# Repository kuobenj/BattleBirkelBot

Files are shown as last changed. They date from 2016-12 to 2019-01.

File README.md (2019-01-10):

# BirkelBot Battlebot Repo
This repository is for the code and other files related to Team Unobtanium's Battlebot for the Combotics competition held annually at the University of Illinois at Urbana Champaign.

Team Unobtanium is:
* Matt Birkel - Team Captain, Mechanical Design, Software
* Benjamin Kuo - Electrical Design, Software

### Folder Structure
* Robot - This is robot side code. For now this should largely be arduino code for the arduino on board the robot.
* DriverStation - This is the operator side code. This is the code that runs on a driverstation computer.
* Arduino_Calibration_Stuff - This is a folder for a tool to use the arduino to calibrate ESC's
* PCB_files is a directory that holds the EAGLE files for the custom "motherboard" for the robot. This directory also features a reworked design of a PCB for hall effect sensors to sensor 35mm outrunner brushless motors.

### Dependencies
The Robot code is written for an Arduino Pro Mini. As such the Arduino IDE is required to compile and upload the Arduino-side code. The Arduino IDE offers a variety of Libraries for use. This project utilizes

* Encoder by Paul Stoffregen (version 1.4.1)
* PID by Brett Beauregard (version 1.2.0)

To install these libraries

- Go to 'Sketch' -> 'Include Library' -> 'Manage Libraries...'
- Search '<package-name>'
- Install '<package-name>'

The DriverStation code is a pythons script. Below are a potentially non-exhaustive list of the required dependencies.

* pygame - For grabbing joystick values
* serial - For writing to the serial out for the Xbee communication

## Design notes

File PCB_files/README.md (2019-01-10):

The sensor_35mm files are all inspired by Equals Zero Designs

"Mount CAD" directory is for the mount to the motor for the sensors

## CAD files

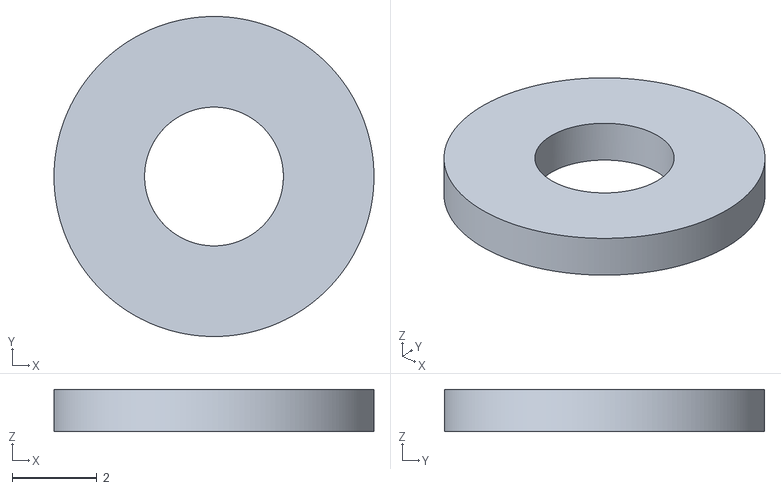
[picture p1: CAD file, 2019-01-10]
PCB_files/Mount CAD/ANSI_4_x_1_mm.stl
7.56 x 7.56 x 1.00

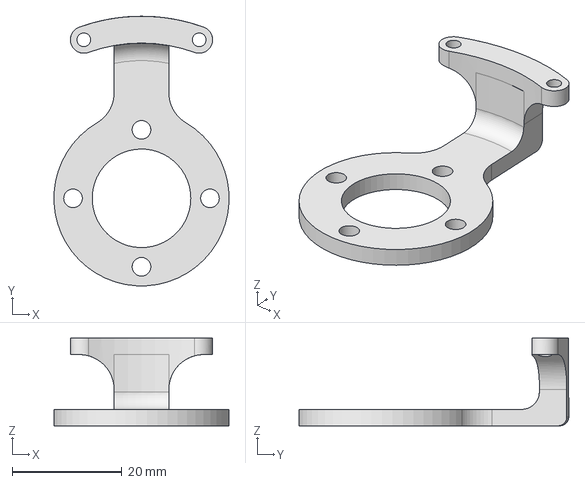
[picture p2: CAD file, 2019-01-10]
PCB_files/Mount CAD/SensorMount.stp
32.0 x 49.2 x 16.0 mm

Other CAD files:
PCB_files/Mount CAD/SensorMount.ipt
PCB_files/Mount CAD/SensorMount.stl

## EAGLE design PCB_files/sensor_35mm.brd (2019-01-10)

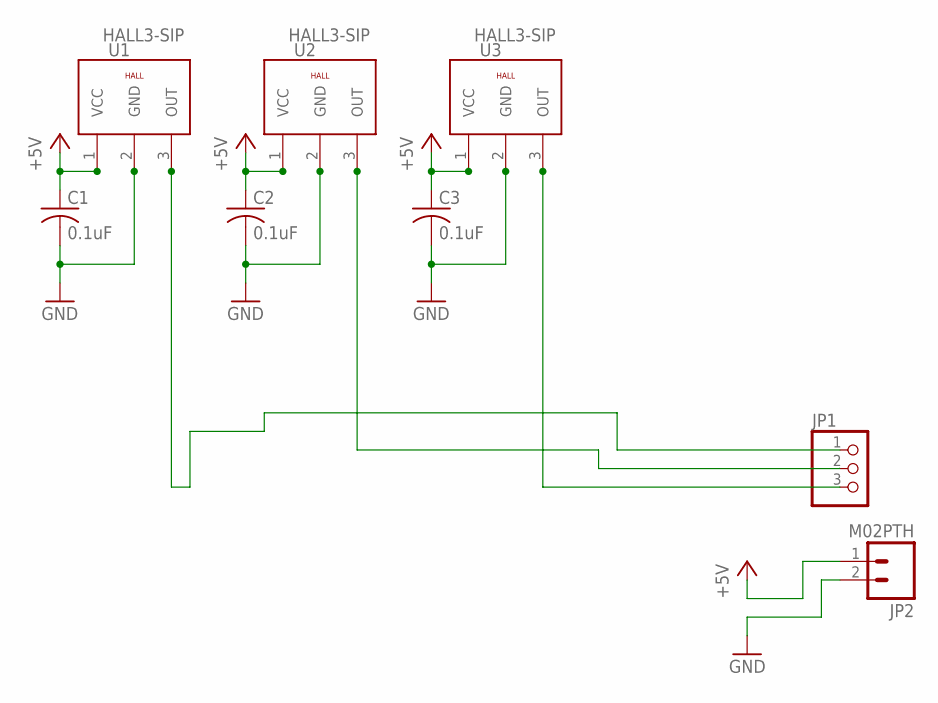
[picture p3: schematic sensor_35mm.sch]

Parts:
C1, C2, C3: 0.1uF; C0603
JP1: PINHD-1X3CB; 1X03-CLEANBIG
JP2: M02PTH; 1X02
U1, U2, U3: HALL3-SIP; 3PINS1,27

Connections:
+5V: C1.1, C2.1, C3.1, JP2.1, U1.1 (VCC), U2.1 (VCC), U3.1 (VCC)
GND: C1.2, C2.2, C3.2, JP2.2, U1.2 (GND), U2.2 (GND), U3.2 (GND)
unnamed: JP1.1, U1.3 (OUT)
unnamed: JP1.3, U3.3 (OUT)
unnamed: JP1.2, U2.3 (OUT)

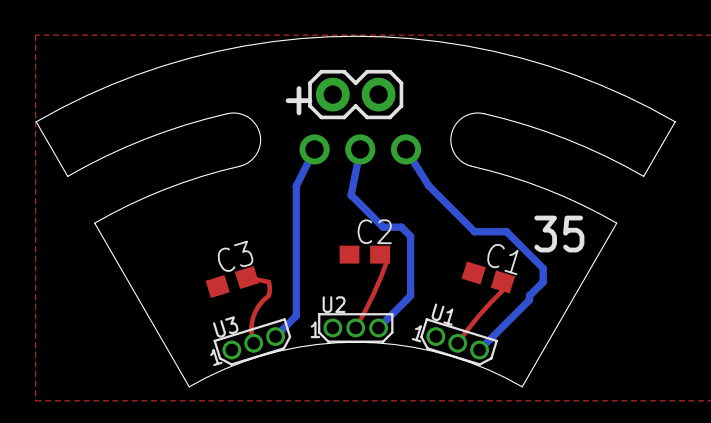
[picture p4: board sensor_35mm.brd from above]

Board: 2 copper layers, 35.5 x 19.5 mm, 8 parts (0 on the bottom side), 5 nets.

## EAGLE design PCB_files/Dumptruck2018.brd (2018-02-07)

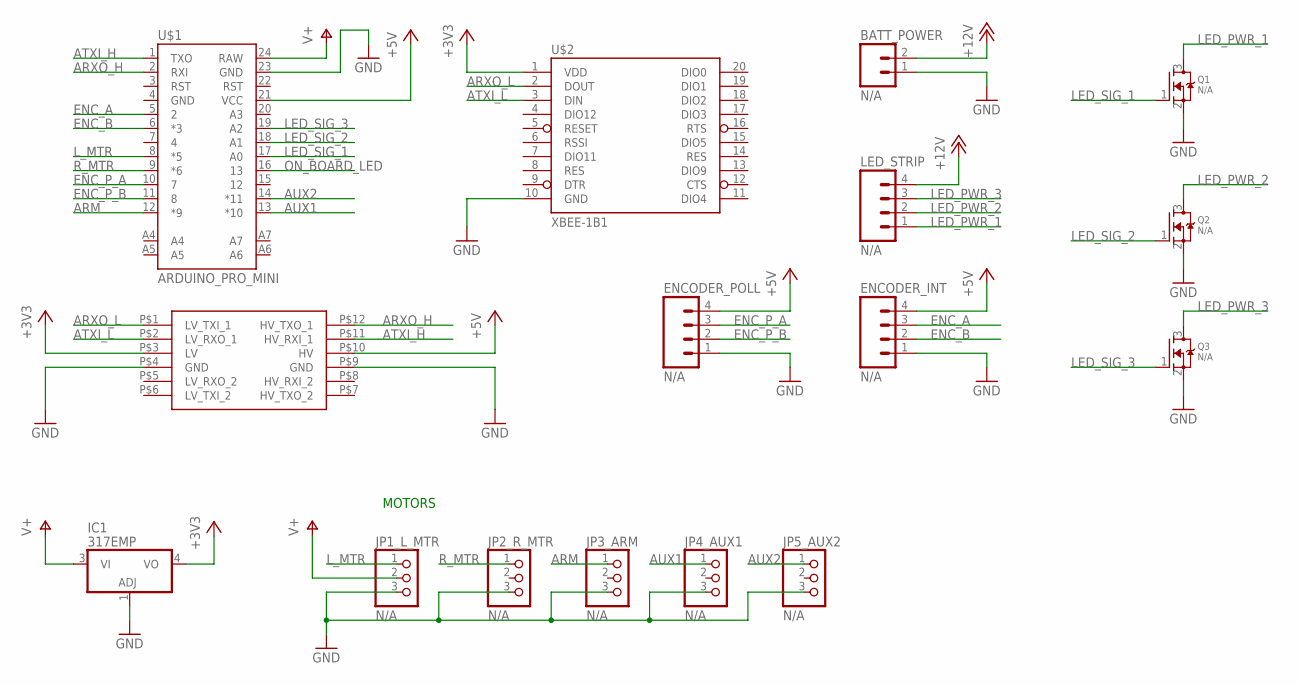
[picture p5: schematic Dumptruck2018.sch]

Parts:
BATT_POWER: N/A; 1X02
ENCODER_INT: N/A; 1X04_LOCK
ENCODER_POLL: N/A; 1X04_LOCK
IC1: 317EMP; SOT223
JP1_L_MTR, JP2_R_MTR, JP3_ARM, JP4_AUX1, JP5_AUX2: N/A; 1X03
LED_STRIP: N/A; 1X04_LOCK
Q1, Q2, Q3: N/A; SOT23
U$1: ARDUINO_PRO_MINI
U$2: XBEE-1B1; XBEE-1
U$3: LOGIC_LEVEL_CONVERTER

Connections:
+3V3: IC1.4 (VO), U$2.1 (VDD), U$3.P$3 (LV)
+5V: ENCODER_INT.4, ENCODER_POLL.4, U$1.21 (VCC), U$3.P$10 (HV)
+12V: BATT_POWER.2, LED_STRIP.4
ARM: JP3_ARM.1, U$1.12 (*9)
ARXO_H: U$1.2 (RXI), U$3.P$12 (HV_TXO_1)
ARXO_L: U$2.2 (DOUT), U$3.P$1 (LV_TXI_1)
ATXI_H: U$1.1 (TXO), U$3.P$11 (HV_RXI_1)
ATXI_L: U$2.3 (DIN), U$3.P$2 (LV_RXO_1)
AUX1: JP4_AUX1.1, U$1.13 (*10)
AUX2: JP5_AUX2.1, U$1.14 (*11)
ENC_A: ENCODER_INT.3, U$1.5 (2)
ENC_B: ENCODER_INT.2, U$1.6 (*3)
ENC_P_A: ENCODER_POLL.3, U$1.10 (7)
ENC_P_B: ENCODER_POLL.2, U$1.11 (8)
GND: BATT_POWER.1, ENCODER_INT.1, ENCODER_POLL.1, IC1.1 (ADJ), JP1_L_MTR.3, JP2_R_MTR.3, JP3_ARM.3, JP4_AUX1.3, JP5_AUX2.3, Q1.2 (S), Q2.2 (S), Q3.2 (S), U$1.23 (GND), U$2.10 (GND), U$3.P$4 (GND), U$3.P$9 (GND)
LED_PWR_1: LED_STRIP.1, Q1.3 (D)
LED_PWR_2: LED_STRIP.2, Q2.3 (D)
LED_PWR_3: LED_STRIP.3, Q3.3 (D)
LED_SIG_1: Q1.1 (G), U$1.17 (A0)
LED_SIG_2: Q2.1 (G), U$1.18 (A1)
LED_SIG_3: Q3.1 (G), U$1.19 (A2)
L_MTR: JP1_L_MTR.1, U$1.8 (*5)
ON_BOARD_LED: U$1.16 (13)
R_MTR: JP2_R_MTR.1, U$1.9 (*6)
V+: IC1.3 (VI), JP1_L_MTR.2, U$1.24 (RAW)

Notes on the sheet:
MOTORS

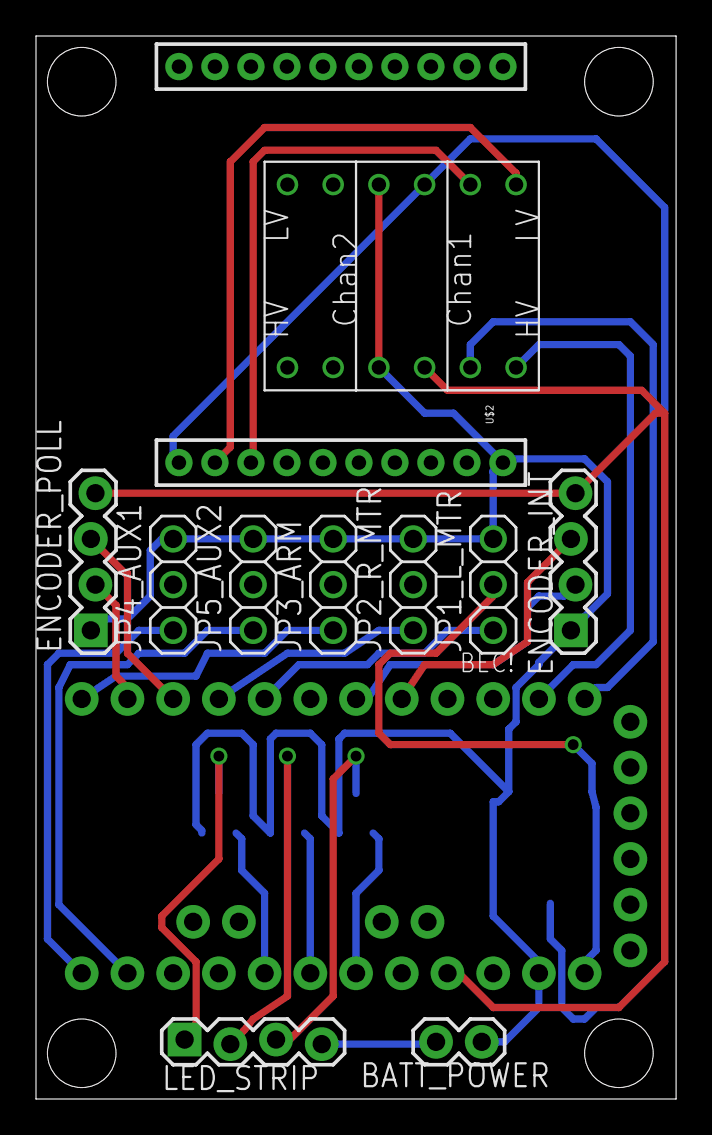
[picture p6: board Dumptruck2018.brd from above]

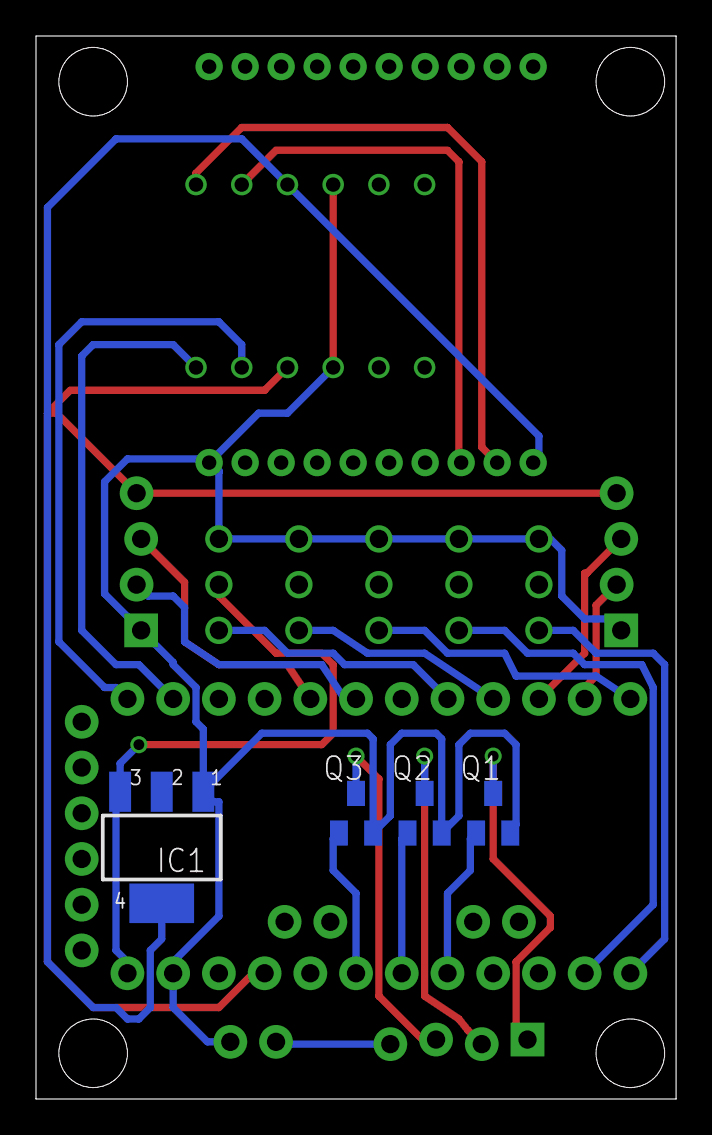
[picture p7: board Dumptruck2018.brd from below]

Board: 2 copper layers, 35.6 x 59.1 mm, 16 parts (4 on the bottom side), 24 nets.

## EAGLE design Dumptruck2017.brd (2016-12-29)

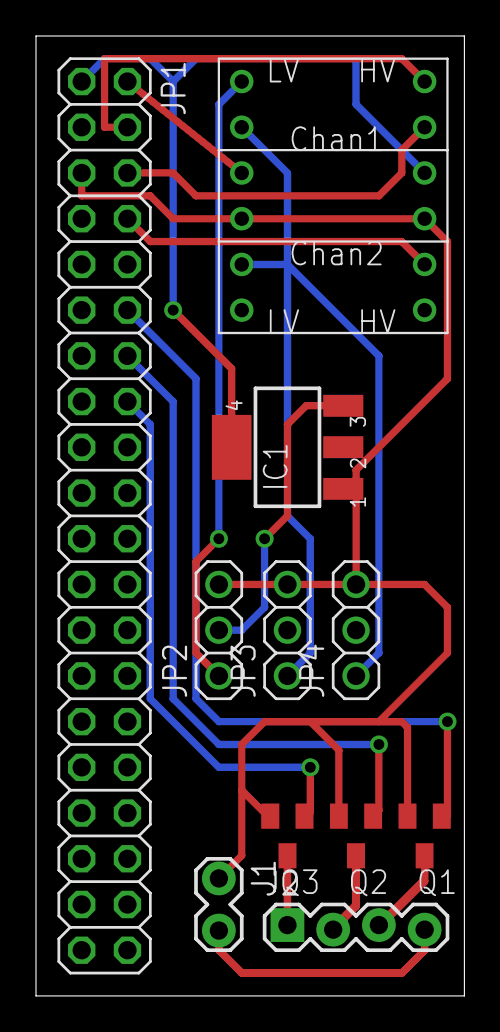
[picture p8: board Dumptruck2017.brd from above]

Board: 2 copper layers, 23.8 x 53.3 mm, 11 parts (0 on the bottom side), 17 nets.

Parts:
IC1: 317EMP; SOT223
J1: 1X02_LOCK
J2: 1X04_LOCK
JP1: 2X20
JP2, JP3, JP4: 1X03
Q1, Q2, Q3: SOT23
U$1: LOGIC_LEVEL_CONVERTER

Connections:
+3V3: JP1.2, U$1.P$3
+5V: IC1.4, JP1.1, U$1.P$10
+12V: J1.2, J2.4
+24V: IC1.3, JP2.2
ARM_MTR_H: JP4.1, U$1.P$5
ARM_MTR_L: JP1.8, U$1.P$8
GND: IC1.1, J1.1, JP1.5, JP2.3, JP3.3, JP4.3, Q1.2, Q2.2, Q3.2, U$1.P$4, U$1.P$9
LED1_PWR: J2.3, Q1.3
LED1_SIG: JP1.12, Q1.1
LED2_PWR: J2.2, Q2.3
LED2_SIG: JP1.14, Q2.1
LED3_PWR: J2.1, Q3.3
LED3_SIG: JP1.16, Q3.1
L_MTR_H: JP2.1, U$1.P$1
L_MTR_L: JP1.4, U$1.P$12
R_MTR_H: JP3.1, U$1.P$2
R_MTR_L: JP1.6, U$1.P$11

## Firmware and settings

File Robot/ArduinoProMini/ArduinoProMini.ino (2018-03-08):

#include <Servo.h>
//#define ENCODER_DO_NOT_USE_INTERRUPTS
#define ENCODER_OPTIMIZE_INTERRUPTS
#include <Encoder.h>
#include <PID_v1.h>

/*==============================GLOBAL VARS===================================*/
//Motor Pins
const unsigned char leftPin = 5;
const unsigned char rightPin = 6;
const unsigned char armPin = 9;

//Aux Pins for Motors or I/O
// const unsigned char aux1Pin = 10;
// const unsigned char aux2Pin = 11;

//Lights
const unsigned char boardLedPin = 13;
//LED Strip
const unsigned char ledPinBlue = 16;
const unsigned char ledPinRed = 14;
const unsigned char ledPinGreen = 15;
enum LEDColor {
  OFF,
  RED,
  GREEN,
  BLUE,
  YELLOW,
  PURPLE,
  BLUEGREEN,
  WHITE
};

//Encoder Pins
const unsigned char inttEncPinA = 2;
const unsigned char inttEncPinB = 3;
// const unsigned char pollEncPinA = 7;
// const unsigned char pollEncPinB = 8;

//Using Servo API for ESCs
Servo leftSrvo;
Servo rightSrvo;
Servo armSrvo;
// Uncomment these if you want to run additional motors
// Servo aux1Srvo;
// Servo aux2Srvo;

// If true, arm input = angle
// If false arm input = motor direction and speed (default)
bool armAngleMode = false;

// The encoder value at which the arm is considered to be
// all the way down at "zero" angle.
int32_t armZeroPoint = 0;

// The multiplier used to convert the arm angle (0 to 250)
// to the desired encoder value.
double armScale = 20;

//Encoders
/* If the Encoder API is not installed in your Arduino Environement:
  - Go to 'Sketch' -> 'Include Library' -> 'Manage Libraries...'
  - Search 'Encoder'
  - Install 'Encoder by Paul Stoffregen' (This project uses version 1.4.1)
*/
Encoder inttEnc(inttEncPinB, inttEncPinA);
// Encoder pollEnc(pollEncPinA, pollEncPinB);

//Interrupt limiting
int interruptsDisabledLoopCount = 0;
int numLoopsBetweenActivatingInterrupts = 1;

//PID object for arm
//TODO: SET GAINS
double myPID_Setpoint, myPID_Input, myPID_Output;
double Kp=0.43, Ki=0.0001, Kd=0.05; //Gains
PID myPID(&myPID_Input, &myPID_Output, &myPID_Setpoint, Kp, Ki, Kd, P_ON_E, DIRECT);

//var for checking if comms are lost
unsigned long lastTimeRX = 0;

// Used for comms protocol
bool waitingForStartByte = true;

//Local testing
int loopCount = 0;

/*=================================SET UP=====================================*/
void setup() {
  //57600 baud, pin 13 is an indicator LED
  pinMode(boardLedPin, OUTPUT);
  Serial.begin(57600);
  Serial.setTimeout(510);

  // Set the modes on the motor pins
  leftSrvo.attach(leftPin);
  rightSrvo.attach(rightPin);
  armSrvo.attach(armPin);

  // Set the modes of the feedback LED pins
  pinMode(ledPinBlue,OUTPUT);
  pinMode(ledPinRed,OUTPUT);
  pinMode(ledPinGreen,OUTPUT);

  // Write initial values to the pins
  leftSrvo.writeMicroseconds(1500);
  rightSrvo.writeMicroseconds(1500);
  armSrvo.writeMicroseconds(1500);
  
  digitalWrite(ledPinBlue, LOW);
  digitalWrite(ledPinRed, LOW);
  digitalWrite(ledPinGreen, LOW);

  // Set Up Arm PID
  //turn the PID on
  myPID_Setpoint = 0.0; //TODO: Change this to meaningful value
  myPID.SetMode(MANUAL);
  myPID.SetOutputLimits(-500, 500);

  // Give a few blinks to show that the code is up and running
  blinkBoardLed(2, 200);
}

/*=================================LOOP=======================================*/
void loop() {
  // Poll the encoder
  //inttEnc.read();

  if (waitingForStartByte) {
    // Look for the start byte (255, or 0xFF)
    if (serialRead() == 255) {
      lastTimeRX = millis();
      waitingForStartByte = false;
    }
  }

  if (!waitingForStartByte && serialAvailable(3)) {
    waitingForStartByte = true;
    // Read the message body (3 bytes)
    int left = serialRead();
    int right = serialRead();
    int arm = serialRead();
    if (left == 126 && right == 126 && arm == 126) {
      processSetup();
    } else if (left < 255 && right < 255 && arm < 255) {
      processCmd(left, right, arm);
    }
  }
 
  if (millis() - lastTimeRX > 250) {
    idle();
  }
}


/*============================CUSTOM FUNC=====================================*/
void processCmd(int left, int right, int arm) {
  // Debug output
//  Serial.print("L: ");
//  Serial.print(left);
//  Serial.print(", R:");
//  Serial.print(right);
//  Serial.print(", A:");
//  Serial.print(arm);
//  Serial.print(", Enc:");
//  Serial.print(inttEnc.read());
//  Serial.print(", Count:");
//  Serial.print(++loopCount);
//  Serial.println("");

  // Indicate that we have signal by illuminating the on-board LED
  digitalWrite(boardLedPin, HIGH);

  // Special values: 123 to 126
  // left/right/arm all == 126 is setup cmd - see main loop
  if (arm == 123) {        // reset current arm encoder value as zero point
    armZeroPoint = inttEnc.read();
    setLEDColor(PURPLE);
  } else if (arm == 124) { // set arm in angle mode
    armAngleMode = true;
    myPID.SetMode(AUTOMATIC);
  } else if (arm == 125) { // set arm in motor mode (default)
    armAngleMode = false;
    myPID.SetMode(MANUAL);
  } else if (armAngleMode) {
    setArmAngle(arm);
  } else {
    moveArm(arm);
  }
  runWheels(left, right);
}

void setArmAngle(int arm) {
  // Omit the reserved values listed in processCmd (123 - 126)
  // so that the arm value represents a contiguous range of values.
  // arm == 127 is valid angle, but represents idle when armAngleMode == false.
  if (arm > 123) arm -= 4;

  // Multiply the desired arm angle by armScale
  // to get the desired encoder angle.
  myPID_Setpoint = ((double) arm) * armScale;

  // Subtract the armZeroPoint from the current encoder value
  // to get the current encoder angle.
  myPID_Input = (double) (inttEnc.read() - armZeroPoint);
  myPID.Compute();

  // Debug output
//  Serial.print("  PID arm: ");
//  Serial.print(arm);
//  Serial.print(", setpoint: ");
//  Serial.print(myPID_Setpoint);
//  Serial.print(", input: ");
//  Serial.print(myPID_Input);
//  Serial.print(", output:");
//  Serial.print((int) 1500 - myPID_Output);
//  Serial.println("");

  // Cap the PID command at the endpoints of the command range
  double armMicroseconds = 1500 - myPID_Output;
  if (armMicroseconds > 2000) armMicroseconds = 2000;
  if (armMicroseconds < 1000) armMicroseconds = 1000;

  armSrvo.writeMicroseconds((int) armMicroseconds);
  setLEDColor(YELLOW);
}

void moveArm(int arm) {
  arm = map(arm, 0, 254, 1000, 2000);
  armSrvo.writeMicroseconds(arm);

  if (arm > 1505) {
    setLEDColor(BLUE);
  } else if(arm < 1495) {
    setLEDColor(GREEN);
  } else {
    setLEDColor(WHITE);
  }
}

void runWheels(int left, int right) {
  left = map(left, 0, 254, 1000, 2000);
  right = map(right, 0, 254, 1000, 2000);

  leftSrvo.writeMicroseconds(left);
  rightSrvo.writeMicroseconds(right);
}

void idle() {
  // Set all motors to neutral
  rightSrvo.writeMicroseconds(1500);
  leftSrvo.writeMicroseconds(1500);
  armSrvo.writeMicroseconds(1500);

  // Indicate that we have lost comms by turning off the on-board LED
  digitalWrite(boardLedPin, LOW);
  setLEDColor(RED);
}

void setLEDColor(LEDColor color) {
  switch (color) {
    case OFF:
      digitalWrite(ledPinRed, LOW);
      digitalWrite(ledPinGreen, LOW);
      digitalWrite(ledPinBlue, LOW);
      break;
    case RED:
      digitalWrite(ledPinRed, HIGH);
      digitalWrite(ledPinGreen, LOW);
      digitalWrite(ledPinBlue, LOW);
      break;
    case GREEN:
      digitalWrite(ledPinRed, LOW);
      digitalWrite(ledPinGreen, HIGH);
      digitalWrite(ledPinBlue, LOW);
      break;
    case BLUE:
      digitalWrite(ledPinRed, LOW);
      digitalWrite(ledPinGreen, LOW);
      digitalWrite(ledPinBlue, HIGH);
      break;
    case YELLOW:
      digitalWrite(ledPinRed, HIGH);
      digitalWrite(ledPinGreen, HIGH);
      digitalWrite(ledPinBlue, LOW);
      break;
    case PURPLE:
      digitalWrite(ledPinRed, HIGH);
      digitalWrite(ledPinGreen, LOW);
      digitalWrite(ledPinBlue, HIGH);
      break;
    case BLUEGREEN:
      digitalWrite(ledPinRed, LOW);
      digitalWrite(ledPinGreen, HIGH);
      digitalWrite(ledPinBlue, HIGH);
      break;
    case WHITE:
      digitalWrite(ledPinRed, HIGH);
      digitalWrite(ledPinGreen, HIGH);
      digitalWrite(ledPinBlue, HIGH);
      break;
  }
}

void blinkLED(int count, int duration, LEDColor color) {
  for (int index = 0; index < count; ++index) {
    setLEDColor(color);
    delay(duration);
    setLEDColor(WHITE);
    delay(duration);
  }
}

void blinkBoardLed(int count, int duration) {
  for (int index = 0; index < count; ++index) {
    digitalWrite(boardLedPin, HIGH);
    delay(duration);
    digitalWrite(boardLedPin, LOW);
    delay(duration);
  }
}

// Specialized command for setting up the PID controller.
// Command format:
//   255, 126, 126, 126,
//     <Proportional char>,    <--- either "E" for proportional on error
//                                      or "M" for proportional on measurement
//     <# chars> <Kp>,         <--- string representing value of Kp
//     <# chars> <Ki>,         <--- string representing value of Ki
//     <# chars> <Kd>,         <--- string representing value of Kd
//     <# chars> <armScale>,   <--- string representing value of armScale
//     <checksum>              <--- sum all chars excluding lengths & 0xFF
void processSetup() {
//  Serial.println("Setup:");

  // Simple checksum
  // If needed, consider Fletcher checksum
  int checksum = 0;

  waitSerialAvailable(1);
  char proportional = serialRead();
  checksum += proportional;
  // Serial.print("  Proportional on error/measurement: ");
  // Serial.println(proportional);

  // Read 4 strings and convert to doubles
  double values[4];
  for (int valueIndex = 0; valueIndex < 4; ++valueIndex) {
    // Read string as # characters followed by characters
    waitSerialAvailable(1);
    int strLen = serialRead();
    char strChars[strLen + 1];
    waitSerialAvailable(strLen);
    for (int strIndex = 0; strIndex < strLen; ++strIndex) {
      char ch = serialRead();
      strChars[strIndex] = ch;
      checksum += ch;
    }
    strChars[strLen] = 0;
    String valueStr = String(strChars);
    values[valueIndex] = valueStr.toDouble();
//     Serial.print("  ");
//     Serial.println(values[valueIndex]);
  }

  // Simple sanity check - abort if checksum does not match
  waitSerialAvailable(1);
  if ((checksum & 0xFF) != serialRead()) {
//    Serial.print("  Checksum did not match. Expected: ");
//    Serial.println(checksum & 0xFF);
    // blinkBoardLed(3, 500);
    blinkLED(3, 250, RED);
    return;
  }

  Kp = values[0];
  Ki = values[1];
  Kd = values[2];
  armScale = values[3];
  int pOn;
  if (proportional == 'E') {
    pOn = P_ON_E;
  } else {
    pOn = P_ON_M;
  }
  myPID.SetTunings(Kp, Ki, Kd, pOn);
//  Serial.println("  PID gains set");
  // blinkBoardLed(5, 50);
  blinkLED(5, 50, PURPLE);
  setLEDColor(PURPLE);
}

/*============================LOCAL TEST=====================================*/
//int serialData[] = {255, 127, 127, 127};
//int serialIndex = 0;
//
//char setupData[][10] = { // max string size + 1 for null terminator
//  {(char) 255, 126, 126, 126, 'E'}, // setup signal + proportional
//  "0.1", // Kp
//  "0", // Ki
//  "0", // Kd
//  "40", // armScale
//};
//int setupChecksum = 152;
//int setupIndex = 0;
//int setupCount = -1;

// Block the main loop until the specified number of bytes is available
void waitSerialAvailable(int count) {
  while (!serialAvailable(count)) {
    delay(1);
  }
}

bool serialAvailable(int count) {
  return Serial.available() >= count;

  // Local test
//  return true;
}

int serialRead() {
  return Serial.read();

//  // Local test
//  // Simulate client setup command
//  if (setupCount >= 0) {
//    while (setupCount < 5) {
//      if (setupIndex == -1) {
//        ++setupIndex;
//        return String(setupData[setupCount]).length();
//      }
//      unsigned char ch = setupData[setupCount][setupIndex++];
//      if (ch != 0) {
//        return ch;
//      }
//      setupIndex = -1;
//      ++setupCount;
//    }
//    setupCount = -1;
//    return setupChecksum;
//  }
//
//  // Simulate joystick input from the keyboard
//  if (Serial.available() > 0) {
//    int serialCmd = Serial.read();
//    Serial.println(serialCmd);
//
//    if (serialCmd == 'c') {               // send setup message
//      setupCount = 0;
//    
//    } else if (serialCmd == 'f') {        // forward
//      serialData[1] = min(serialData[1] + 10, 254);
//      serialData[2] = min(serialData[2] + 10, 254);
//    } else if (serialCmd == 'g') {        // forward small
//      serialData[1] = min(serialData[1] + 2, 254);
//      serialData[2] = min(serialData[2] + 2, 254);
//    } else if (serialCmd == 'h') {        // forward full
//      serialData[1] = 254;
//      serialData[2] = 254;
//    } else if (serialCmd == 's') { // stop
//      serialData[1] = 127;
//      serialData[2] = 127;
//    } else if (serialCmd == 'r') { // reverse
//      serialData[1] = max(serialData[1] - 10, 0);
//      serialData[2] = max(serialData[2] - 10, 0);
//    } else if (serialCmd == 't') { // reverse small
//      serialData[1] = max(serialData[1] - 2, 0);
//      serialData[2] = max(serialData[2] - 2, 0);
//    } else if (serialCmd == 'y') { // reverse full
//      serialData[1] = 0;
//      serialData[2] = 0;
//      
//    } else if (serialCmd == 'u') {        // up
//      serialData[3] = min(serialData[3] + 10, 254);
//    } else if (serialCmd == 'i') {        // up small
//      serialData[3] = min(serialData[3] + 2, 254);
//    } else if (serialCmd == 'o') {        // up full
//      serialData[3] = 254;
//    } else if (serialCmd == 'm') { // stop
//      serialData[3] = 127;
//    } else if (serialCmd == 'j') { // down
//      serialData[3] = max(serialData[3] - 10, 0);
//    } else if (serialCmd == 'k') { // down small
//      serialData[3] = max(serialData[3] - 2, 0);
//    } else if (serialCmd == 'l') { // down full
//      serialData[3] = 0;
//      
//    } else if (serialCmd == 'q') { // arm up
//      int arm = min(serialData[3] + 1, 250);
//      if (arm >= 123 && arm <= 126) arm = 127;
//      serialData[3] = arm;
//    } else if (serialCmd == 'a') { // arm down
//      int arm = max(serialData[3] - 1, 0);
//      if (arm >= 123 && arm <= 126) arm = 127;
//      serialData[3] = arm;
//    } else if (serialCmd == '1') { // set arm angle to 1 degree
//      serialData[3] = 1;
//    } else if (serialCmd == '5') { // set arm angle to 124 degree
//      serialData[3] = 127;
//    } else if (serialCmd == '9') { // set arm angle to 250 degree
//      serialData[3] = 254;
//    } else if (serialCmd == 'z') { // set arm zero point
//      serialData[3] = 123;
//    } else if (serialCmd == 'x') { // toggle arm angle/motor mode
//      if (!armAngleMode) {
//        serialData[3] = 124;
//      } else {
//        serialData[3] = 125;
//      }
//    }
//  }
//  int value = serialData[serialIndex];
//  ++serialIndex;
//  if (serialIndex > 3) {
//    serialIndex = 0;
//  }
//  return value;
}

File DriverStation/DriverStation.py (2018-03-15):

#!/usr/bin/env python

from enum import Enum
import pygame
import time
import os
import serial
import array
import sys
import math

# To check what serial ports are available in Linux, use the bash command: dmesg | grep tty
# To check what serial ports are available in Windows, use the cmd command: wmic path Win32_SerialPort
#    OR go to Device Manager > Ports (COM & LPT)
comPort = 'COM5'
ser = serial.Serial(comPort, 57600, timeout=1)

### CONTROL SCHEME ###
# Drive:
#   Arcade Drive, i.e.
#     Left joystick Y-axis -- forward/reverse
#     Right joystick X-axis -- turn/arc
#
# Arm:
#  In manual mode...
#    Right trigger -- arm up (analog control)
#    Left trigger -- arm down (analog control)
#    Start button -- consider the current position the new "down" position for auto mode
#    Press either bumper -- enter auto mode
#  In auto mode...
#    Nothing -- arm goes to "down" position
#    Hold one bumper (either one) -- arm goes to "over bumps" position
#    Hold both bumpers -- arm goes to "up" position
#    Press either trigger -- kick out to manual mode
#    A button -- kick out to manual mode
#######################

# Set the channel numbers for various controls
BUTTON_IDS_ARM_AUTO = [4, 5]  # Buttons used to control arm in auto mode
BUTTON_ID_EXIT_AUTO = 0  # Button used to forcefully exit auto mode
BUTTON_ID_RESET_ARM_POS = 7  # Button used to zero the arm position
BUTTON_ID_SEND_PID_GAINS = 6  # Button used to transmit the PID gains stored in this script
                              # (different from what the robot might have as its own defaults)
AXIS_ID_ARM_MANUAL = 2  # Analog triggers for manual arm control
BUTTON_ID_STOP_PROGRAM = 1

class ArmMode(Enum):
    AUTO = 0
    MANUAL = 1

# Set the preset values for automatic arm control
ARM_POS_DOWN = 0
ARM_POS_OVER_BUMPS = 10
ARM_POS_UP = 80

# Set the PID gains (only transmitted when hitting the "send PID gains" button)
PID_ERROR_OR_MEASUREMENT = 'E'  # 'E' for error, 'M' for measurement
PID_P_GAIN = "0.43"  # Must be a double in string format
PID_I_GAIN = "0.0001"  # Must be a double in string format
PID_D_GAIN = "0.05"  # Must be a double in string format
ARM_SCALE_FACTOR = "20"  # Must be a double in string format

# Set the reserved values for communicating special signals to the robot.
# NOTE: Reserved values are selected around 127 ("zero motor power") since those values are rarely
#       used because it takes more power than that to overcome the motor and gearbox resistance.
RESERVED_VALUES_MAX = 126  # The highest reserved value
RESERVED_VALUES_MIN = 123  # The lowest reserved value
RESERVED_VALUE_ENTER_ARM_AUTO = 124
RESERVED_VALUE_ENTER_ARM_MANUAL = 125
RESERVED_VALUE_RESET_ARM_POS = 123
RESERVED_VALUE_SET_PID_GAINS = 126

# Set the number of times to transmit each mode change message
RESEND_COUNT_MODE_CHANGE = 3

def main():

    global ser

    # Initialize the gamepad
    pygame.init()
    joysticks = []
    for i in range(0, pygame.joystick.get_count()):
        joysticks.append(pygame.joystick.Joystick(i))
        joysticks[-1].init()
        print("Detected joystick '",joysticks[-1].get_name(),"'")

    # Local variables
    prevDriveMtrCmds = {'left':0, 'right':0}
    prevArmCmd = RESERVED_VALUE_ENTER_ARM_MANUAL
    prevArmFlags = 0
    prevTimeSent = 0
    prevArmMode = ArmMode.MANUAL
    currArmMode = ArmMode.MANUAL
    transmitXTimes = RESEND_COUNT_MODE_CHANGE
    done = False
    loopCounter = 0

    try:
        while (done == False):

            pygame.event.pump()  # This line is needed to process the gamepad packets

            if joystickWatchdog(joysticks[0]):
                sendNeutralCommand()
                continue

            ##### WHEEL COMMANDS #####

            # Get the raw values for drive translation/rotation using the gamepad.
            yRaw = joysticks[0].get_axis(1)   # Y-axis translation comes from the left joystick Y axis
            rRaw = -joysticks[0].get_axis(4)  # Rotation comes from the right joystick X axis

            # Get the drive motor commands for Arcade Drive
            driveMtrCmds = arcadeDrive(yRaw, rRaw)
            driveMtrCmds['left'] = 255 - driveMtrCmds['left']
            driveMtrCmds['right'] = 255 - driveMtrCmds['right']

            # Protect against sending a reserved value
            if driveMtrCmds['left'] == RESERVED_VALUE_SET_PID_GAINS:
                driveMtrCmds['left'] = RESERVED_VALUE_SET_PID_GAINS + 1
            if driveMtrCmds['right'] == RESERVED_VALUE_SET_PID_GAINS:
                driveMtrCmds['right'] = RESERVED_VALUE_SET_PID_GAINS + 1

            ##########################

            ###### ARM COMMAND #######

            # Get the raw values for the arm using the gamepad
            armRawManual = joysticks[0].get_axis(AXIS_ID_ARM_MANUAL)
            armAutoNumBtns = (1 if joysticks[0].get_button(BUTTON_IDS_ARM_AUTO[0]) else 0) + \
                               (1 if joysticks[0].get_button(BUTTON_IDS_ARM_AUTO[1]) else 0)
            armBtnExitAuto = joysticks[0].get_button(BUTTON_ID_EXIT_AUTO)
            armBtnZero = joysticks[0].get_button(BUTTON_ID_RESET_ARM_POS)
            armBtnSendPIDGains = joysticks[0].get_button(BUTTON_ID_SEND_PID_GAINS)

            (rawArmCmd, currArmMode) = armDrive(armRawManual, armAutoNumBtns, armBtnExitAuto, prevArmMode)

            if transmitXTimes > 0:
                armCmd = prevArmCmd
            elif currArmMode == ArmMode.MANUAL and prevArmMode == ArmMode.AUTO:
                armCmd = RESERVED_VALUE_ENTER_ARM_MANUAL
                transmitXTimes = RESEND_COUNT_MODE_CHANGE
            elif currArmMode == ArmMode.AUTO and prevArmMode == ArmMode.MANUAL:
                armCmd = RESERVED_VALUE_ENTER_ARM_AUTO
                transmitXTimes = RESEND_COUNT_MODE_CHANGE
            elif armBtnZero:
                armCmd = RESERVED_VALUE_RESET_ARM_POS
                transmitXTimes = RESEND_COUNT_MODE_CHANGE
            elif armBtnSendPIDGains:
                armCmd = RESERVED_VALUE_SET_PID_GAINS
                # To reset the PID gains, all 3 motor commands (left, right, arm) need to be set to the reserved value
                driveMtrCmds['left'] = RESERVED_VALUE_SET_PID_GAINS
                driveMtrCmds['right'] = RESERVED_VALUE_SET_PID_GAINS
            else:
                if RESERVED_VALUES_MIN <= rawArmCmd and rawArmCmd <= RESERVED_VALUES_MAX:
                    armCmd = RESERVED_VALUES_MAX + 1
                else:
                    armCmd = rawArmCmd

            prevArmMode = currArmMode

            ##########################
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

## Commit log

2016-02-23 Added initial driver station scripts, based on Moser's code from 2015
2016-12-29 eagle cad pcb stuff added
    [Dumptruck2017.brd, Dumptruck2017.sch]
2017-01-01 made some changes to the arm code
2017-01-01 made final changes to shrink board a bit and ordered this version
    [Dumptruck2017.brd]
2017-02-24 Moved/renamed things around a bit
    [Dumptruck2017.brd, Dumptruck2017.sch]
2017-02-24 Copied the arcadeDrive code from the RPiZero python into the DriverStation python. Updated the arm command to use the same exponential control as the drive commands. Added comments.
2017-02-24 Removed the 'mid' motor code from the ArduinoProMini. Still need to add changing LEDs based on arm raise/lower.
2017-02-28 changed pins to new pin outs, also added LED control code
2017-12-11 adding calibration file, not sure what that's for
2017-12-12 old inventor file for some rev of the pcb, committing but will delete later
    [PCB.ipt, PCB.stp]
2017-12-12 removing files not relevant to this year
    [Dumptruck2017.brd, Dumptruck2017.sch, PCB.ipt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]
2017-12-12 remapped the pins, added some comments, added encoder code
2017-12-26 a couple of returns added, no major changes
2017-12-28 wrote some preliminary code for PID, definitely will need more work
2018-02-07 adding PCB_files
    [Dumptruck2018.brd, Dumptruck2018.sch]
2018-02-12 Confirm and rename LED strip pins
2018-02-19 Added Auto/Manual mode for arm. Auto has 3 positions (lowest, low, high), depending on number of buttons pressed. Manual allows to control speed using analog triggers. There is also a function to res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
    [DriverStation.py]
2018-02-19 Read extra flags command in Arduino code, and hold manual/auto and zero states.
2018-02-26 Add arm cmds for client to set Kp, Ki, Kd PID values
2018-02-28 Add remote setup cmd for PID gains
2018-02-28 Add arm angle mode
2018-03-01 Quick cleanup of Arduino_Calibration_Stuff
2018-03-03 Changes for auto/manual arm mode and reserved values
2018-03-05 Added manual bumper control, sending of PID gains setup message, bugfixes, and LED colors on Arduino
    [ArduinoProMini.ino, DriverStation.py]
2018-03-05 Removed some print lines/unused code
2018-03-08 Tuned PID gains, send mode on DS bootup, changed control scheme
2018-03-08 Added default PID gains from tuning, altered comms protocol to re-sync when off sync
2018-03-08 Added joystick watchdog for failsafe
    [DriverStation.py]
2018-03-15 Flipped motors after recalibrating ESCs
    [DriverStation.py]
2019-01-10 Adding Sensor Board Files and Updating README
    This year an additional PCB was needed for use for
    brushless motors. A sensor board was not made for
    35mm motors and this commit contains those files.
    [ANSI_4_x_1_mm.stl, Points.xlsx, SensorMount.ipt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]

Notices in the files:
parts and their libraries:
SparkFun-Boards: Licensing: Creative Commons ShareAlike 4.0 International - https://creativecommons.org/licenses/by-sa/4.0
